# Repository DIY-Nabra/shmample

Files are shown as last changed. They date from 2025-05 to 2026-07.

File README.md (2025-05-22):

Sh'mample
=========

Sh'mample is a shift register driven sample and hold sequencer, capable of rungling.
Inspired in equal parts by the Ciat-Lonbarde Man with the Red Steam, and the Buchla 264.

For use with Ciat-Lonbarde instruments.

[Guide](assets/guide.md)

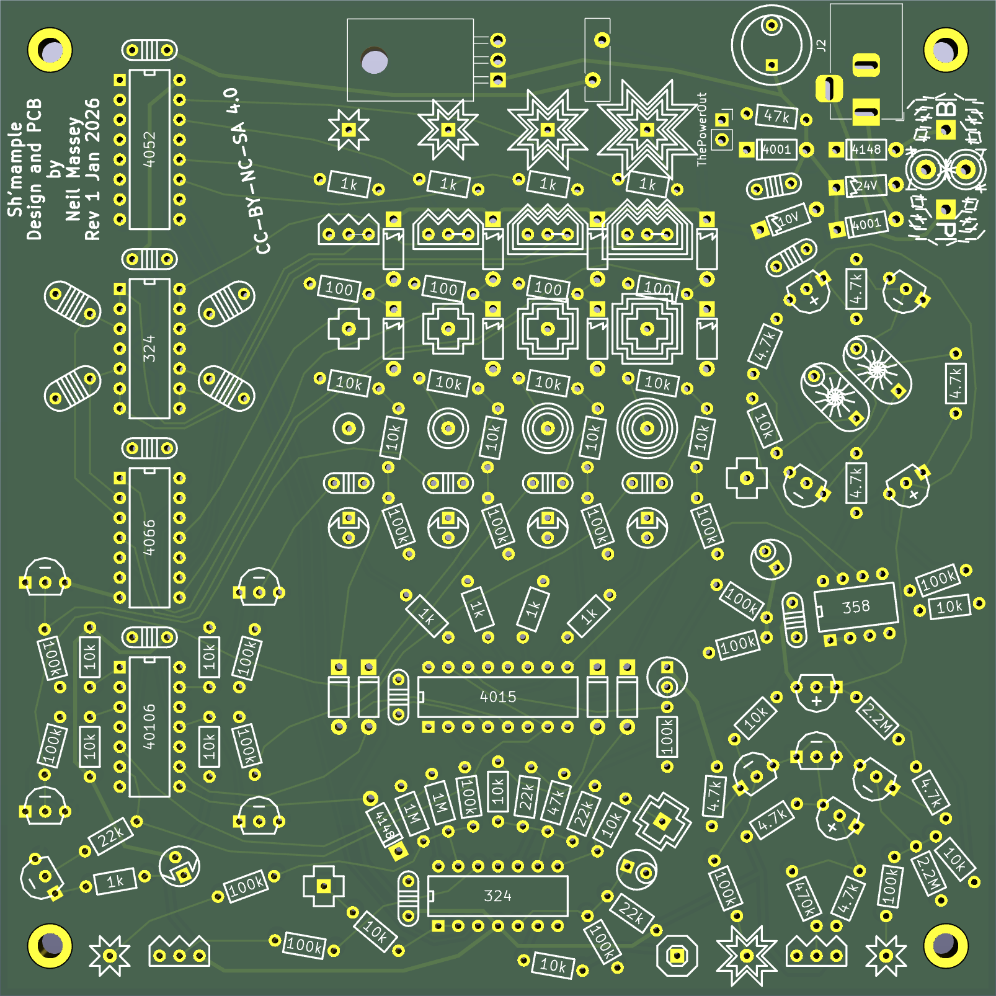
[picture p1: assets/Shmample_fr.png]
Shmample Front

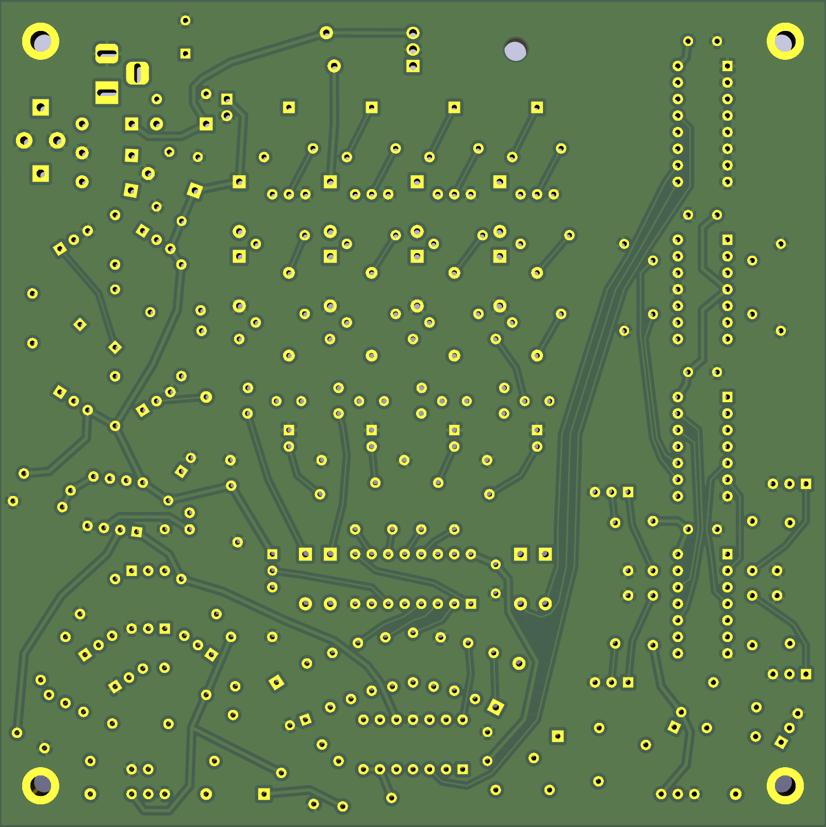
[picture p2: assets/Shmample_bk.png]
Shmample Back


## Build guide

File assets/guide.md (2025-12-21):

Sh'mample Guide
===============

Sh'mample consists of several circuit blocks, interacting:

1.  A clock, with rate nob control, plus verso and inverso inputs.  The special brown node is indicated on the circuit board.  Whether to connect it up is left as user choice.
2.  A comparator, deciding the input for the shift-register, comparing the Data In node with the Data Sense nob.  If nothing is connected here, the 2nd output from the shift register is taken as default input to the Data In node.
3.  A shift-register, driven by the clock.  If the default data input is taken, then the sample-and-hold will advance one stage at a time, tick-tock tick-tock.
4.  A four stage sample and hold, driven by the shift-register.  The Square Inputs provide the signals.  If the default data input is taken, then each stage will be sampled in turn, changing its output every 4th clock tick.  The attenuators can reduce the output sampled voltage.
5.  A single stage Selected Out.  If the default data input is taken, then each stage will be output here one after the other, just after it is sampled.  If an output is attenuated then it will also be attenuated when selected.
6.  Buffered outputs for each sample and hold at the Star Outputs.

Voltage references are provided so that stage 5 can act as a sequencer, outputting a different voltage each clock tick.  The attenuators on the outputs, in conjuction with the voltage reference, allows quite a conventional 4 stage sequencer to be patched.

The real fun happens when you plug something into the data input, where it acts something like a Klee sequencer, but sampling and holding between 1 and 4 sources per clock tick, and changing the selected output based on the contents of the shift-register.

The Circular Spike Inputs can be used to override the shift-register at each sample-and-hold.  Send a signal here to force that stage to sample-and-hold from the Square Input and present the signal at the Star Outputs.  These nodes are androgynous, and will also output a gate signal.

The Power Out can be used to power another board.  Such as the Fourses Tarp, for which this circuit was designed for.

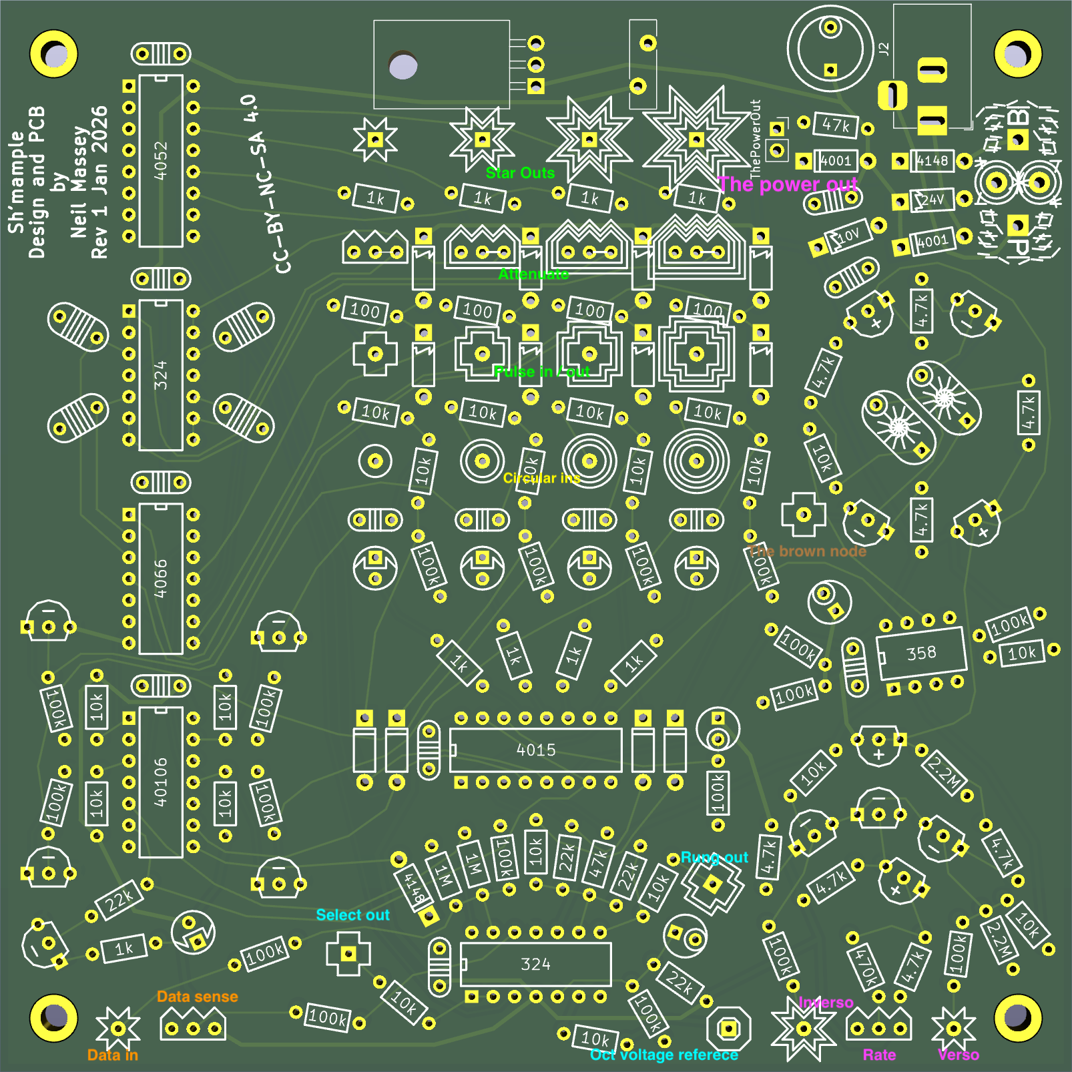
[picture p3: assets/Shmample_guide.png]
Shmample Guide


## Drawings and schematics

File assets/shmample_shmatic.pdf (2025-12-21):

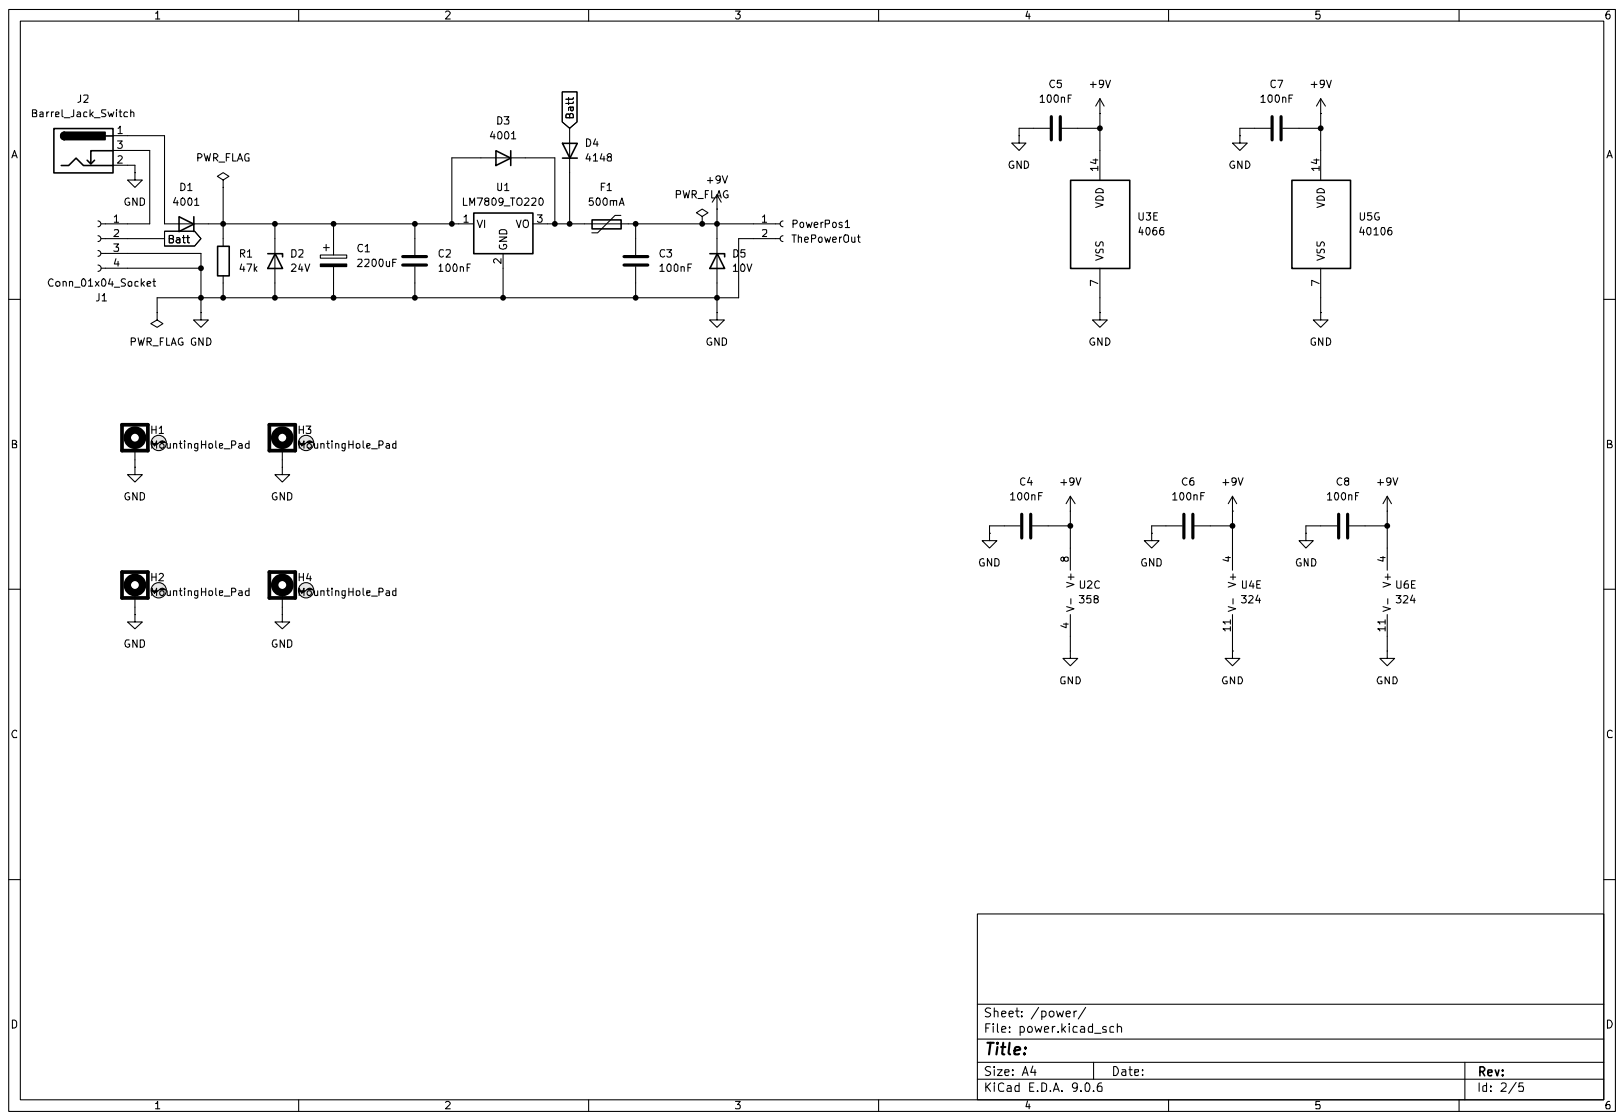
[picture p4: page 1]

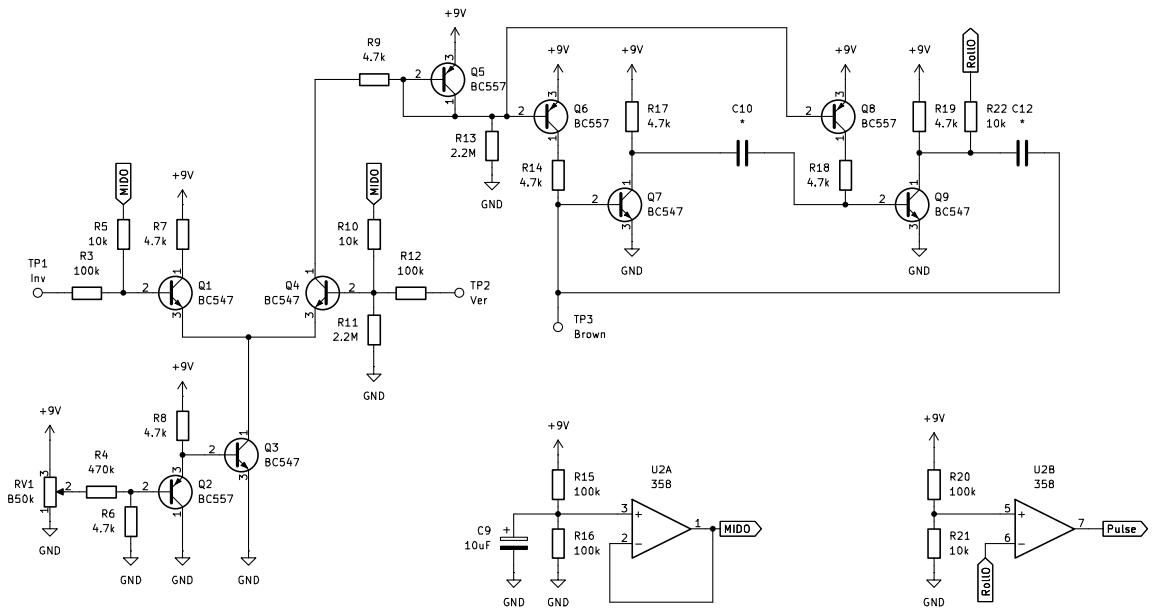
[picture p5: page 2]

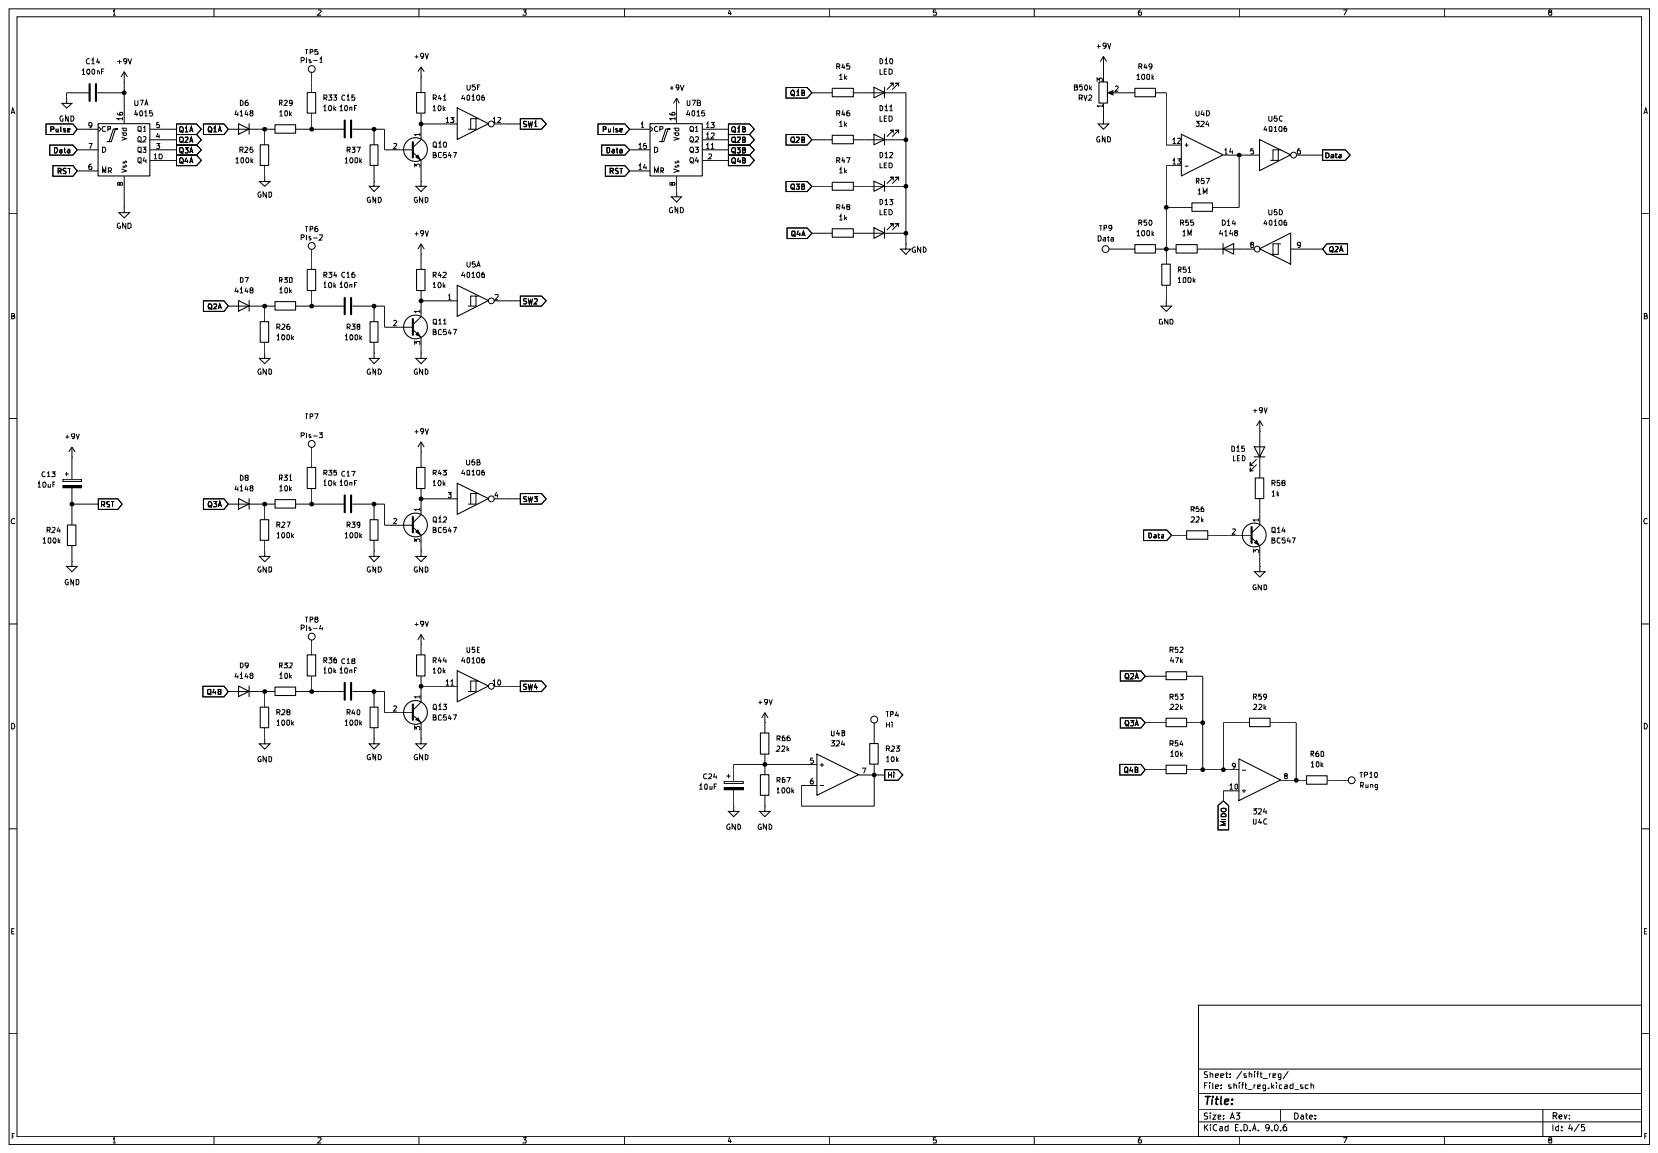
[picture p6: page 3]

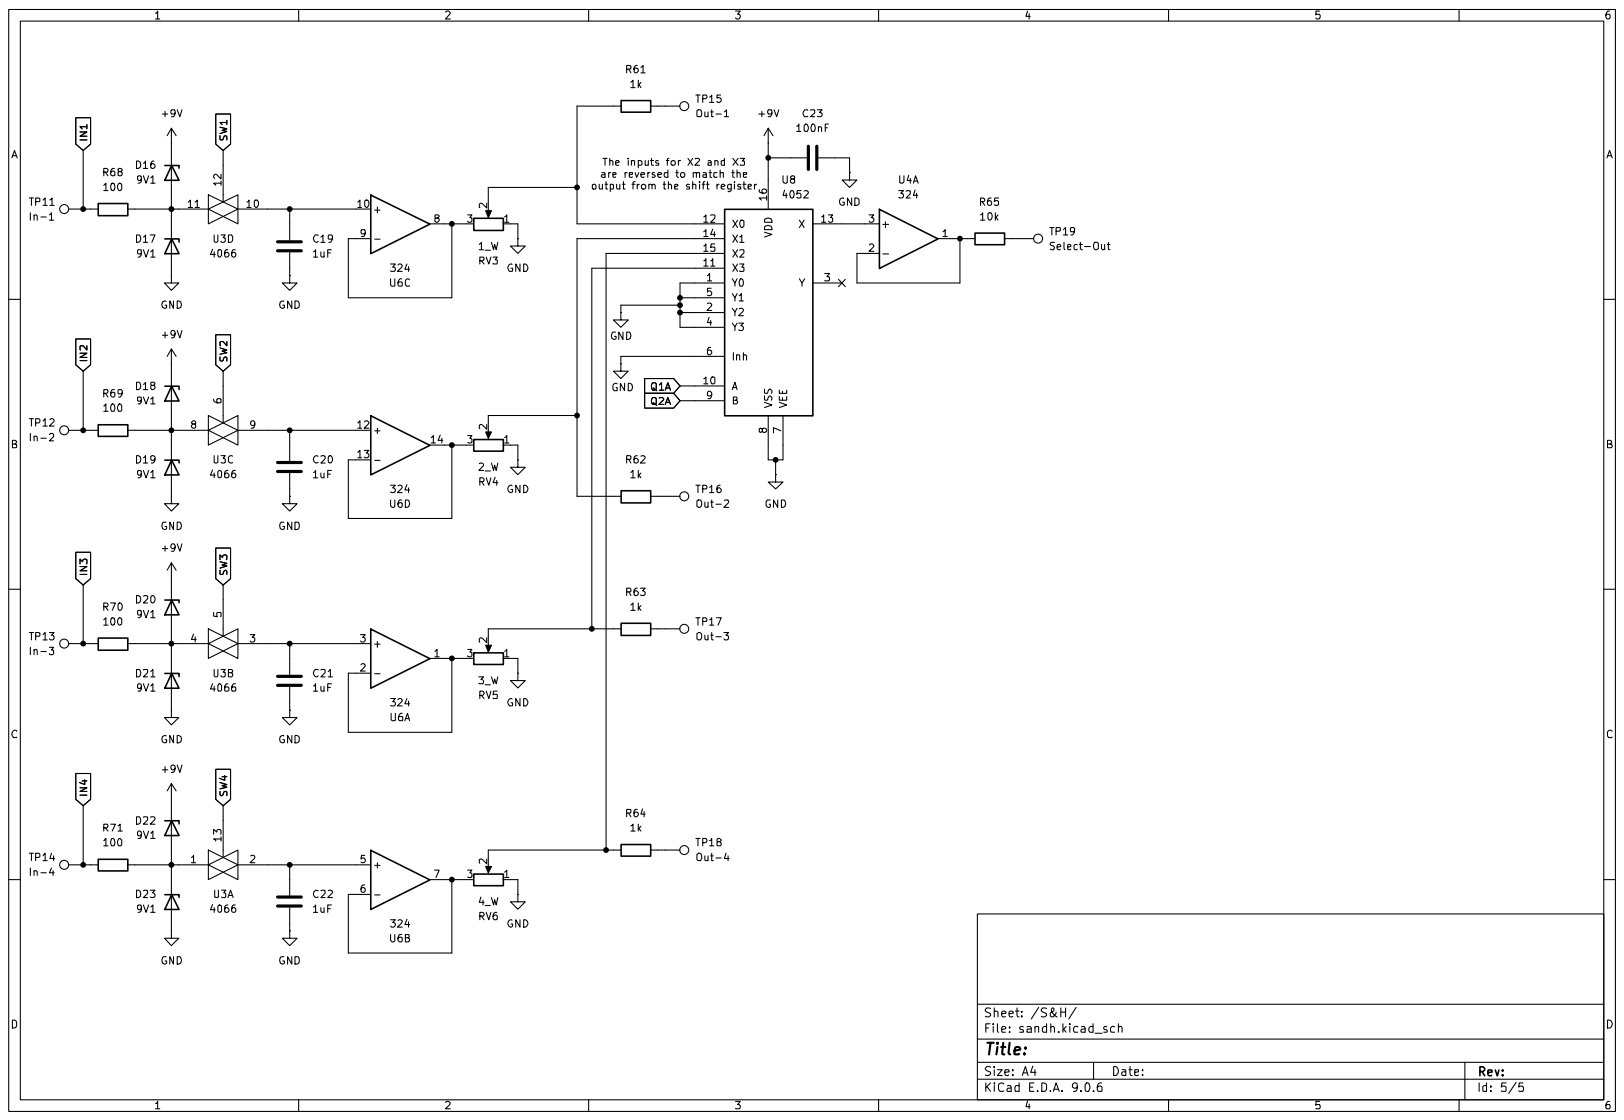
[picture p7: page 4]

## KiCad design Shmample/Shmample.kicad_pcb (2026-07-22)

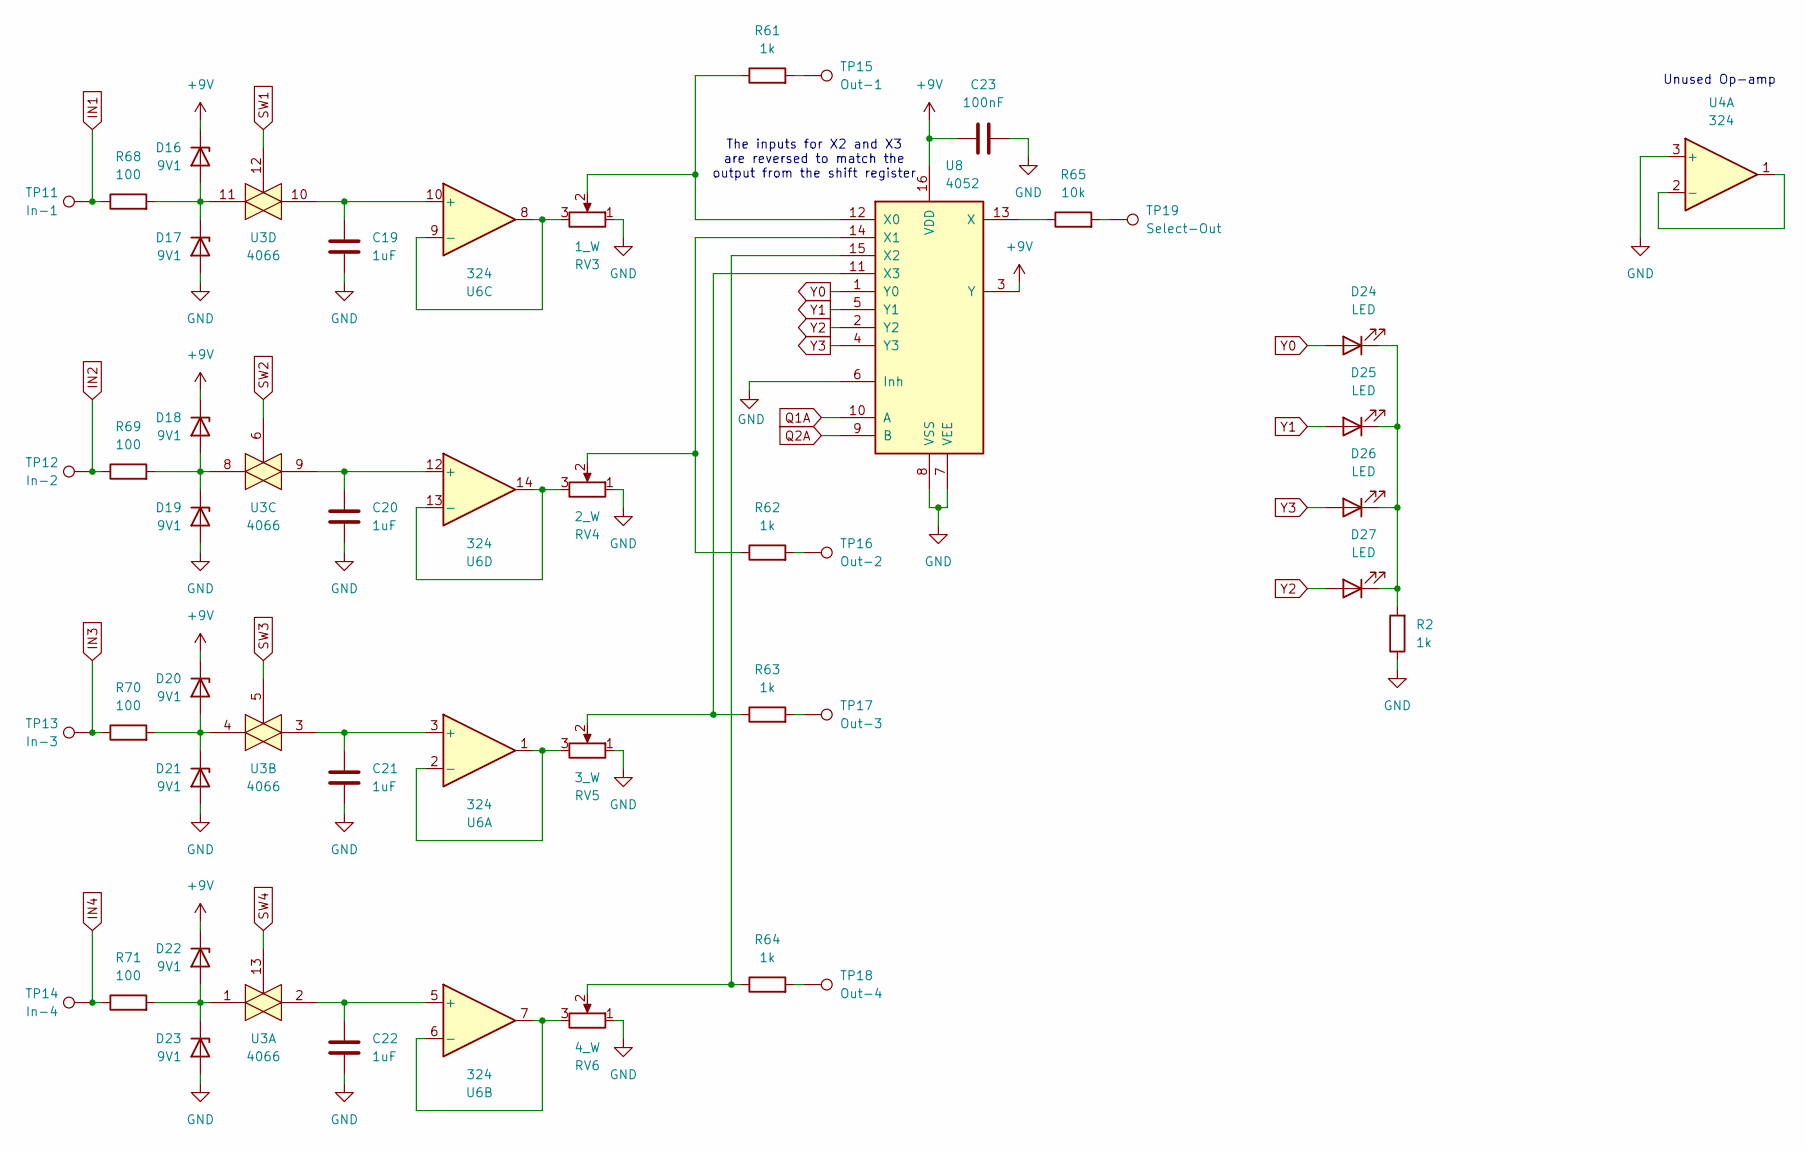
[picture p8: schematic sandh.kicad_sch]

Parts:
C19, C20, C21, C22: 1uF; cpoly105
C23: 100nF; cpoly104_small
D16, D17, D18, D19, D20, D21, D22, D23: 9V1; doz3
D24, D25, D26, D27: LED; led
R2, R61, R62, R63, R64: 1k; r3
R65: 10k; r3
R68, R69, R70, R71: 100; r3
RV3: 1_W; wnob1
RV4: 2_W; wnob2
RV5: 3_W; wnob3
RV6: 4_W; wnob4
TP11: In-1; wsquin
TP12: In-2; wsqout
TP13: In-3; wsqu3in
TP14: In-4; wsqu4in
TP15: Out-1; wtrin
TP16: Out-2; wtrin2
TP17: Out-3; wtrin3
TP18: Out-4; wtrin4
TP19: Select-Out; wsqout
U3: 4066; dip14
U4, U6: 324; dip14
U8: 4052; dip16

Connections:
+9V: C23.1, D16.1 (K), D18.1 (K), D20.1 (K), D22.1 (K), U8.3 (Y), U8.16 (VDD); also elsewhere on the board
GND: C19.2, C20.2, C21.2, C22.2, C23.2, D17.2 (A), D19.2 (A), D21.2 (A), D23.2 (A), R2.1, RV3.1, RV4.1, RV5.1, RV6.1, U4.3 (+), U8.6 (Inh), U8.7 (VEE), U8.8 (VSS); also elsewhere on the board
IN1: R68.1, TP11.1
IN2: R69.1, TP12.1
IN3: R70.1, TP13.1
IN4: R71.1, TP14.1
unnamed: D16.2 (A), D17.1 (K), R68.2, U3.11
unnamed: D18.2 (A), D19.1 (K), R69.2, U3.8
unnamed: D20.2 (A), D21.1 (K), R70.2, U3.4
unnamed: D22.2 (A), D23.1 (K), R71.2, U3.1
unnamed: D24.1 (K), D25.1 (K), D26.1 (K), D27.1 (K), R2.2
unnamed: R61.2, TP15.1
unnamed: R62.2, TP16.1
unnamed: R63.2, TP17.1
unnamed: R64.2, TP18.1
unnamed: R65.2, TP19.1
unnamed: U4.1, U4.2 (-)
unnamed: C21.1, U3.3, U6.3 (+)
unnamed: RV5.3, U6.1, U6.2 (-)
unnamed: C22.1, U3.2, U6.5 (+)
unnamed: RV6.3, U6.6 (-), U6.7
unnamed: C19.1, U3.10, U6.10 (+)
unnamed: RV3.3, U6.8, U6.9 (-)
unnamed: C20.1, U3.9, U6.12 (+)
unnamed: RV4.3, U6.13 (-), U6.14
unnamed: R61.1, RV3.2, U8.12 (X0)
unnamed: R62.1, RV4.2, U8.14 (X1)
unnamed: R64.1, RV6.2, U8.15 (X2)
unnamed: R63.1, RV5.2, U8.11 (X3)
unnamed: R65.1, U8.13 (X)
Q1A: U8.10 (A); also elsewhere on the board
Q2A: U8.9 (B); also elsewhere on the board
SW1: U3.12; also elsewhere on the board
SW2: U3.6; also elsewhere on the board
SW3: U3.5; also elsewhere on the board
SW4: U3.13; also elsewhere on the board
Y0: D24.2 (A), U8.1 (Y0)
Y1: D25.2 (A), U8.5 (Y1)
Y2: D27.2 (A), U8.2 (Y2)
Y3: D26.2 (A), U8.4 (Y3)

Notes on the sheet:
The inputs for X2 and X3 are reversed to match the output from the shift register
Unused Op-amp

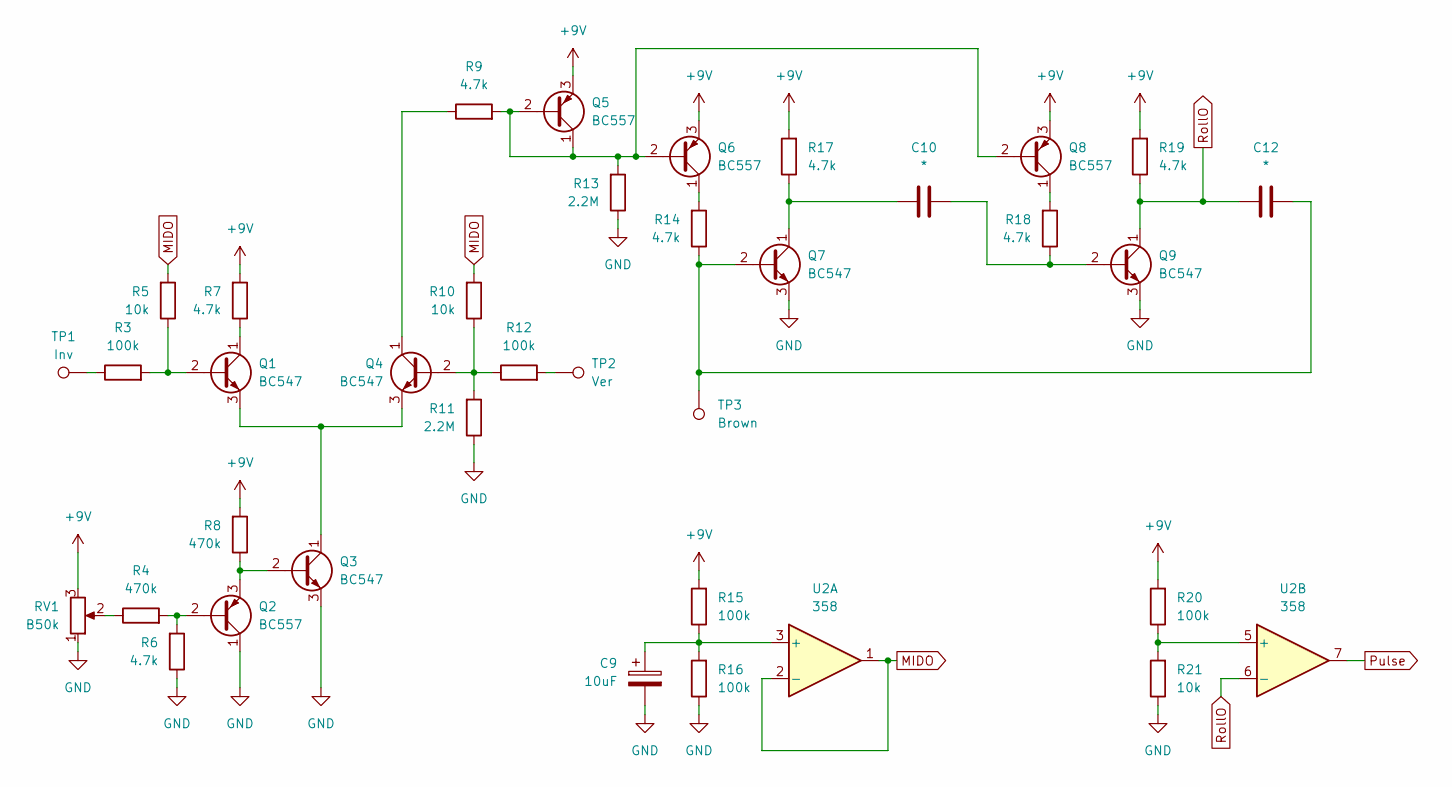
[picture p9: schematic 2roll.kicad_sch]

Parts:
C9: 10uF; cel1
C10, C12: *; chairy
Q1, Q3, Q4, Q7, Q9: BC547; qnpn
Q2, Q5, Q6, Q8: BC557; qpnp
R3, R12, R15, R16, R20: 100k; r3
R4, R8: 470k; r3
R5, R10, R21: 10k; r3
R6, R7, R9, R14, R17, R18, R19: 4.7k; r3
R11, R13: 2.2M; r3
RV1: B50k; wnob
TP1: Inv; wtrin2
TP2: Ver; wtrin
TP3: Brown; wsquin
U2: 358; dip8

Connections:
+9V: Q5.3 (E), Q6.3 (E), Q8.3 (E), R7.2, R8.2, R15.2, R17.2, R19.2, R20.2, RV1.3; also elsewhere on the board
GND: C9.2, Q2.1 (C), Q3.3 (E), Q7.3 (E), Q9.3 (E), R6.1, R11.1, R13.1, R16.1, R21.1, RV1.1; also elsewhere on the board
MIDO: R5.2, R10.2, U2.1, U2.2 (-); also elsewhere on the board
unnamed: Q1.2 (B), R3.2, R5.1
unnamed: Q1.1 (C), R7.1
unnamed: Q1.3 (E), Q3.1 (C), Q4.3 (E)
unnamed: Q2.2 (B), R4.2, R6.2
unnamed: Q2.3 (E), Q3.2 (B), R8.1
unnamed: Q4.2 (B), R10.1, R11.2, R12.1
unnamed: Q4.1 (C), R9.1
unnamed: Q5.1 (C), Q5.2 (B), Q6.2 (B), Q8.2 (B), R9.2, R13.2
unnamed: Q6.1 (C), R14.2
unnamed: C12.2, Q7.2 (B), R14.1, TP3.1
unnamed: C10.1, Q7.1 (C), R17.1
unnamed: Q8.1 (C), R18.2
unnamed: C10.2, Q9.2 (B), R18.1
unnamed: R3.1, TP1.1
unnamed: R4.1, RV1.2
unnamed: R12.2, TP2.1
unnamed: C9.1, R15.1, R16.2, U2.3 (+)
unnamed: R20.1, R21.2, U2.5 (+)
Pulse: U2.7; also elsewhere on the board
RollO: C12.1, Q9.1 (C), R19.1, U2.6 (-)

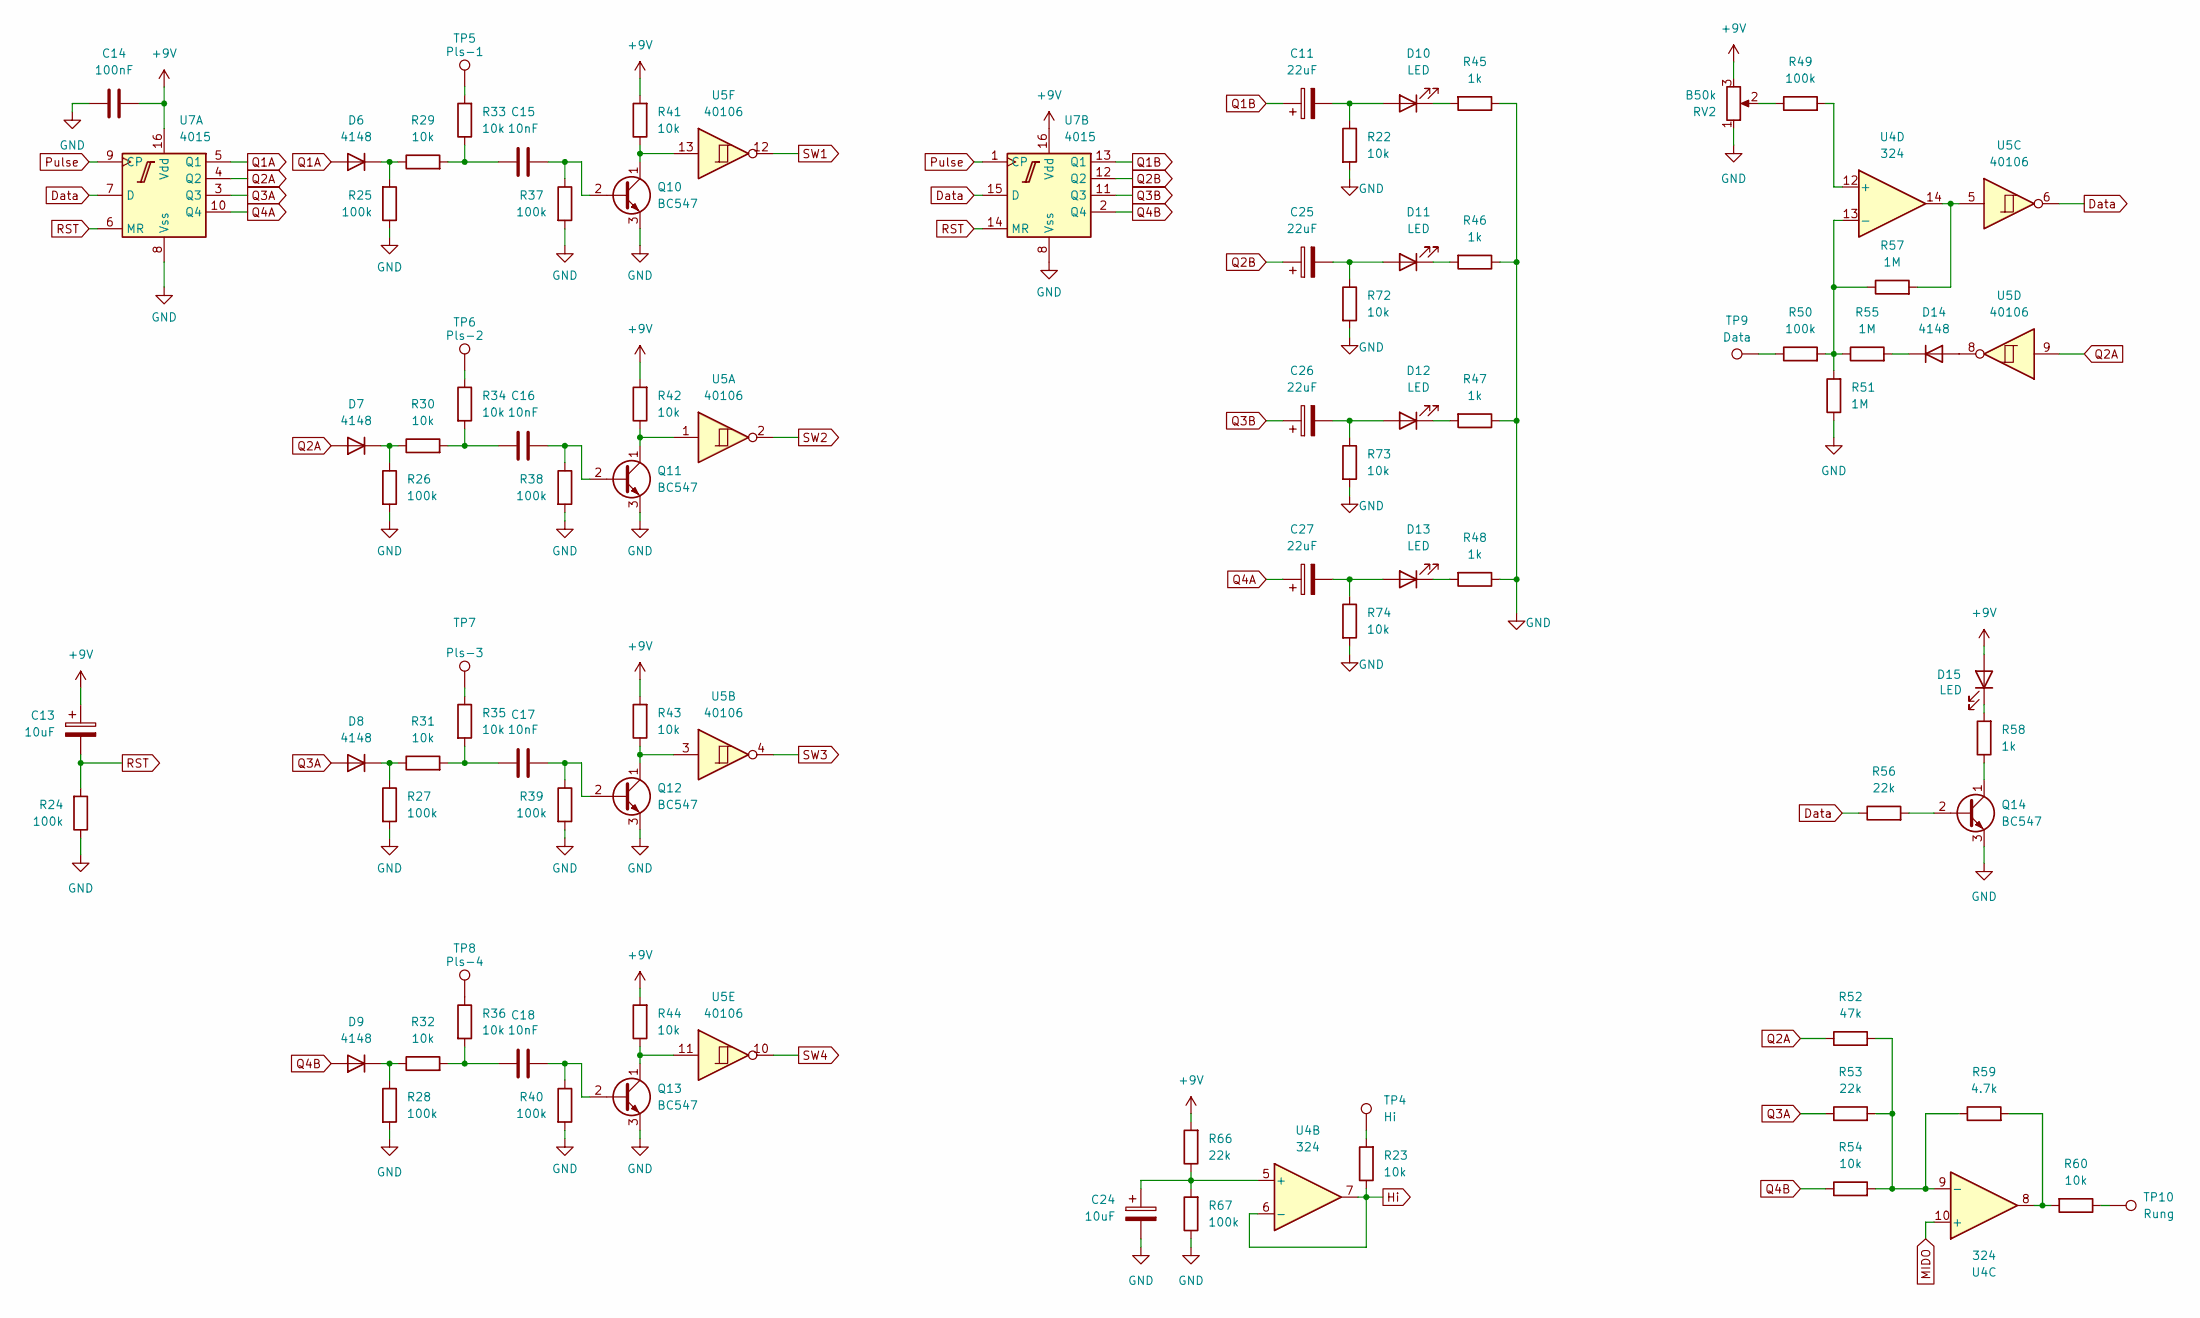
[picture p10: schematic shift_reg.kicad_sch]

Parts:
C11, C25, C26, C27: 22uF; cel1
C13, C24: 10uF; cel1
C14: 100nF; cpoly104_small
C15, C16, C17, C18: 10nF; cpoly103
D6, D7, D8, D9, D14: 4148; do3
D10, D11, D12, D13, D15: LED; led
Q10, Q11, Q12, Q13, Q14: BC547; qnpn
R22, R23, R29, R30, R31, R32, R33, R34, R35, R36, R41, R42, R43, R44, R54, R60, R72, R73, R74: 10k; r3
R24, R25, R26, R27, R28, R37, R38, R39, R40, R49, R50, R67: 100k; r3
R45, R46, R47, R48, R58: 1k; r3
R51, R55, R57: 1M; r3
R52: 47k; r3
R53, R56, R66: 22k; r3
R59: 4.7k; r3
RV2: B50k; wnob
TP4: Hi; wvout
TP5: Pls-1; wcircin
TP6: Pls-2; wcirc2in
TP7: Pls-3; wcirc3in
TP8: Pls-4; wcirc4in
TP9: Data; wtrin
TP10: Rung; wsqu2in
U4: 324; dip14
U5: 40106; dip14
U7: 4015; dip16

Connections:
+9V: C13.1, C14.2, D15.2 (A), R41.2, R42.2, R43.2, R44.2, R66.2, RV2.3, U7.16 (Vdd); also elsewhere on the board
Data: R56.1, U5.6, U7.7 (D), U7.15 (D)
GND: C14.1, C24.2, Q10.3 (E), Q11.3 (E), Q12.3 (E), Q13.3 (E), Q14.3 (E), R22.2, R24.1, R25.1, R26.2, R27.2, R28.2, R37.2, R38.2, R39.2, R40.2, R45.1, R46.1, R47.1, R48.1, R51.1, R67.1, R72.2, R73.2, R74.2, RV2.1, U7.8 (Vss); also elsewhere on the board
Hi: R23.1, U4.6 (-), U4.7
MIDO: U4.10 (+); also elsewhere on the board
unnamed: C15.1, R29.2, R33.1
unnamed: C16.1, R30.2, R34.2
unnamed: C17.1, R31.2, R35.2
unnamed: C18.1, R32.2, R36.2
unnamed: D6.1 (K), R25.2, R29.1
unnamed: D7.1 (K), R26.1, R30.1
unnamed: D8.1 (K), R27.1, R31.1
unnamed: D9.1 (K), R28.1, R32.1
unnamed: C11.2, D10.2 (A), R22.1
unnamed: D10.1 (K), R45.2
unnamed: C25.2, D11.2 (A), R72.1
unnamed: D11.1 (K), R46.2
unnamed: C26.2, D12.2 (A), R73.1
unnamed: D12.1 (K), R47.2
unnamed: C27.2, D13.2 (A), R74.1
unnamed: D13.1 (K), R48.2
unnamed: D14.2 (A), U5.8
unnamed: D14.1 (K), R55.2
unnamed: D15.1 (K), R58.2
unnamed: C15.2, Q10.2 (B), R37.1
unnamed: Q10.1 (C), R41.1, U5.13
unnamed: C16.2, Q11.2 (B), R38.1
unnamed: Q11.1 (C), R42.1, U5.1
unnamed: C17.2, Q12.2 (B), R39.1
unnamed: Q12.1 (C), R43.1, U5.3
unnamed: C18.2, Q13.2 (B), R40.1
unnamed: Q13.1 (C), R44.1, U5.11
unnamed: Q14.2 (B), R56.2
unnamed: Q14.1 (C), R58.1
unnamed: R23.2, TP4.1
unnamed: R33.2, TP5.1
unnamed: R34.1, TP6.1
unnamed: R35.1, TP7.1
unnamed: R36.1, TP8.1
unnamed: R49.1, RV2.2
unnamed: R50.1, TP9.1
unnamed: R57.2, U4.14, U5.5
unnamed: R59.2, R60.2, U4.8
unnamed: R60.1, TP10.1
unnamed: C24.1, R66.1, R67.2, U4.5 (+)
unnamed: R52.2, R53.2, R54.2, R59.1, U4.9 (-)
unnamed: R49.2, U4.12 (+)
unnamed: R50.2, R51.2, R55.1, R57.1, U4.13 (-)
Pulse: U7.1 (CP), U7.9 (CP); also elsewhere on the board
Q1A: D6.2 (A), U7.5 (Q1); also elsewhere on the board
Q1B: C11.1, U7.13 (Q1)
Q2A: D7.2 (A), R52.1, U5.9, U7.4 (Q2); also elsewhere on the board
Q2B: C25.1, U7.12 (Q2)
Q3A: D8.2 (A), R53.1, U7.3 (Q3)
Q3B: C26.1, U7.11 (Q3)
Q4A: C27.1, U7.10 (Q4)
Q4B: D9.2 (A), R54.1, U7.2 (Q4)
RST: C13.2, R24.2, U7.6 (MR), U7.14 (MR)
SW1: U5.12; also elsewhere on the board
SW2: U5.2; also elsewhere on the board
SW3: U5.4; also elsewhere on the board
SW4: U5.10; also elsewhere on the board

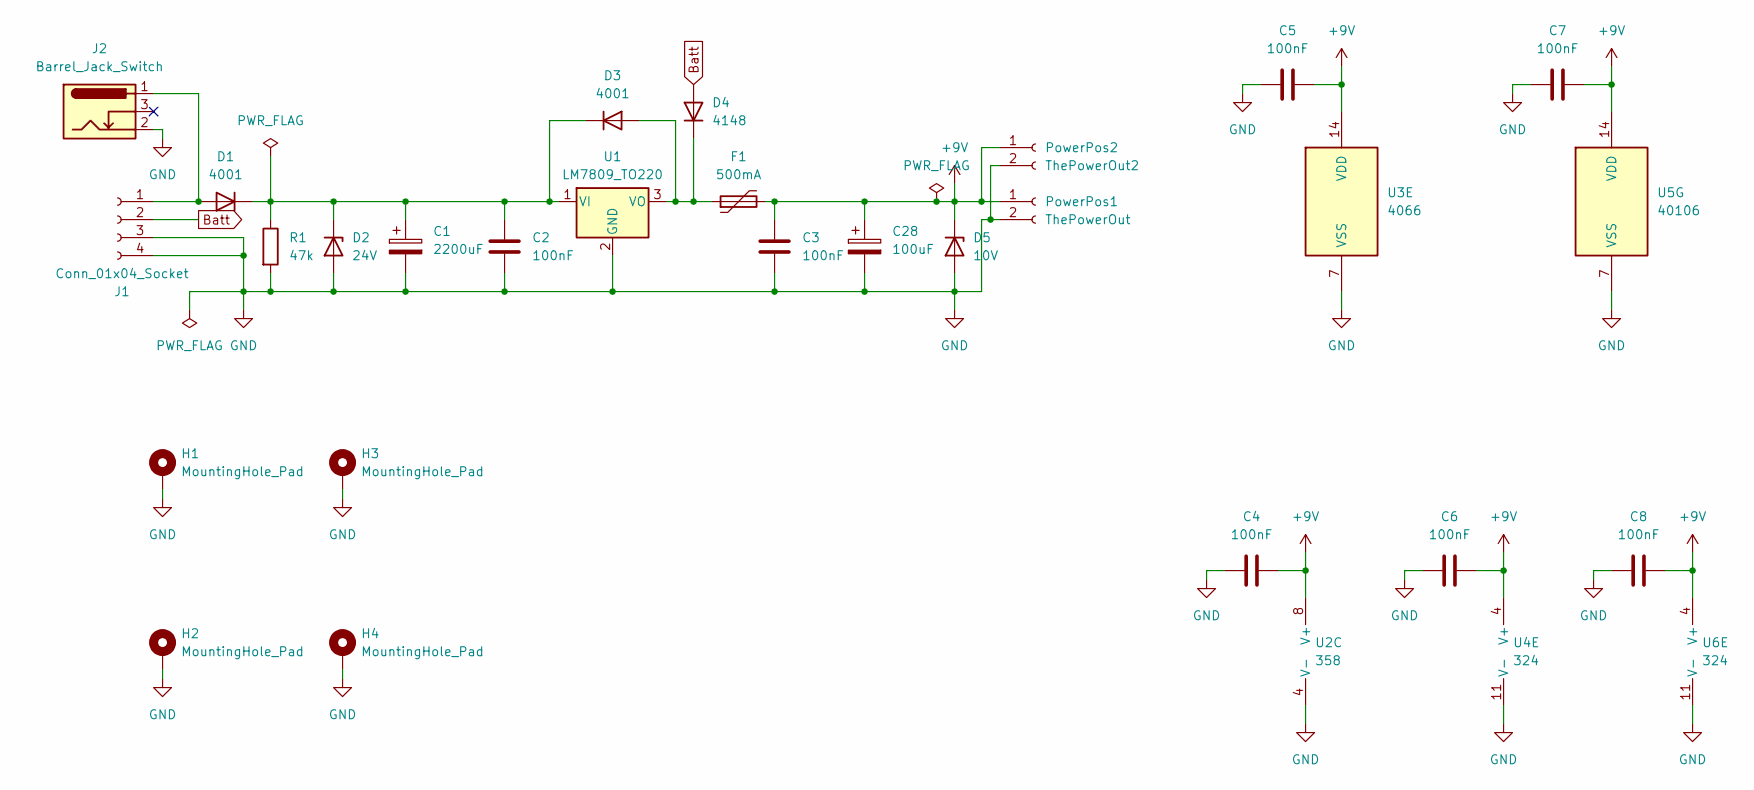
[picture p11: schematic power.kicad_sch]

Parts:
C1: 2200uF; cel2
C2, C3, C4, C5, C6, C7, C8: 100nF; cpoly104_small
C28: 100uF; cel2
D1, D3: 4001; do3
D2: 24V; doz3
D4: 4148; do3
D5: 10V; doz3
F1: 500mA; Fuse_Bourns_MF-RG500
H1, H2, H3, H4: MountingHole_Pad; MountingHole_3.2mm_M3_ISO7380_Pad
J1: Conn_01x04_Socket; powern
J2: Barrel_Jack_Switch; BarrelJack_Horizontal
PowerPos1: ThePowerOut; PinSocket_1x02_P2.54mm_Vertical
PowerPos2: ThePowerOut2; PinSocket_1x02_P2.54mm_Vertical
R1: 47k; r3
U1: LM7809_TO220; TO-220F-3_Horizontal_TabDown
U2: 358; dip8
U3: 4066; dip14
U4, U6: 324; dip14
U5: 40106; dip14

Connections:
+9V: C3.1, C4.2, C5.2, C6.2, C7.2, C8.2, C28.1, D5.1 (K), F1.2, PowerPos1.1, PowerPos2.1, U2.8 (V+), U3.14 (VDD), U4.4 (V+), U5.14 (VDD), U6.4 (V+); also elsewhere on the board
Batt: D4.2 (A), J1.2
GND: C1.2, C2.2, C3.2, C4.1, C5.1, C6.1, C7.1, C8.1, C28.2, D2.2 (A), D5.2 (A), H1.1, H2.1, H3.1, H4.1, J1.3, J1.4, J2.2, PowerPos1.2, PowerPos2.2, R1.2, U1.2 (GND), U2.4 (V-), U3.7 (VSS), U4.11 (V-), U5.7 (VSS), U6.11 (V-); also elsewhere on the board
unnamed: D1.2 (A), J1.1, J2.1
unnamed: C1.1, C2.1, D1.1 (K), D2.1 (K), D3.1 (K), R1.1, U1.1 (VI)
unnamed: D3.2 (A), D4.1 (K), F1.1, U1.3 (VO)

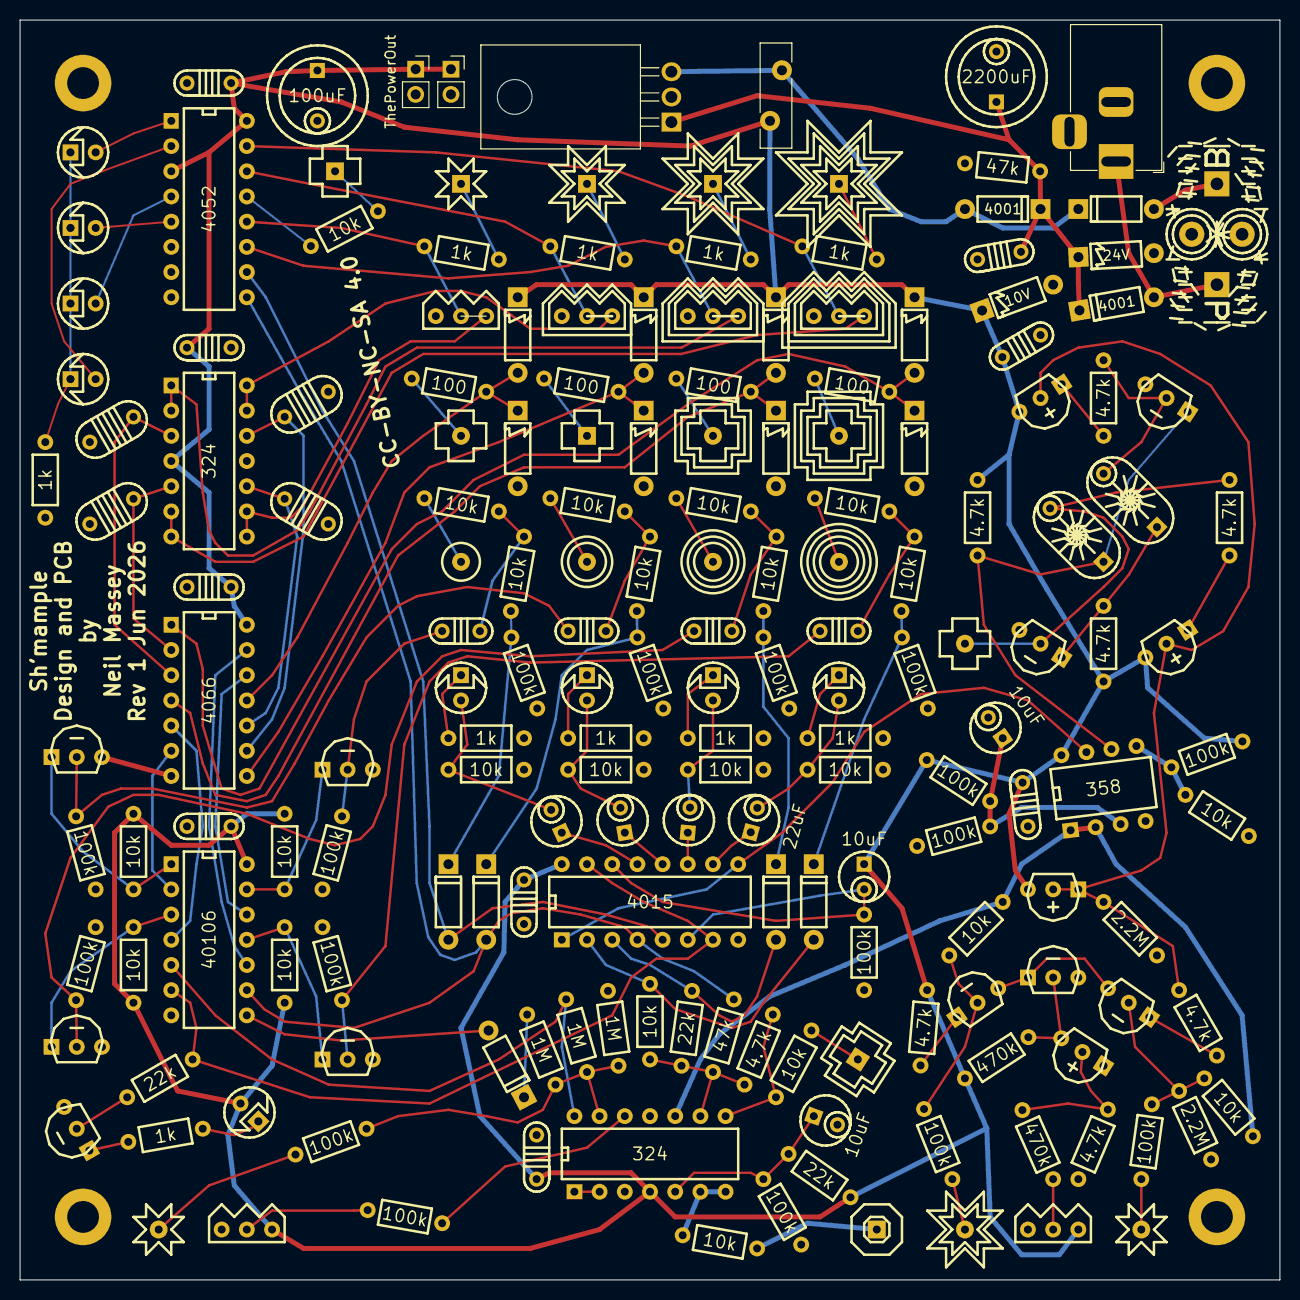
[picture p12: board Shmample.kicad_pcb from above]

Board: 2 copper layers, 127.0 x 127.0 mm, 185 parts (0 on the bottom side), 117 nets.

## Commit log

2025-05-22 Moved Shmample
    [Shmample.kicad_pcb, Shmample.kicad_sch]
2025-06-02 Added attenuators
    [Shmample.kicad_pcb, Shmample.kicad_sch]
2025-06-05 Rotated a pot. That is all
    [Shmample.kicad_pcb]
2025-06-05 Plussed up
    [Shmample.kicad_pcb]
2025-06-06 ironed out some kinky tracks
    [Shmample.kicad_pcb]
2025-11-24 Revision 1
    [2roll.kicad_sch, Shmample.kicad_pcb, Shmample.kicad_sch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]
2025-12-14 Big Pads
    [2roll.kicad_sch, Shmample.kicad_pcb, power.kicad_sch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]
2025-12-21 Added shmatic
    [Shmample.kicad_pcb, power.kicad_sch, sandh.kicad_sch]
2025-12-21 Just moved the rollz down a bit
    [Shmample.kicad_pcb]
2026-01-18 Final revision of revision 1 before manufacture
    [2roll.kicad_sch, Shmample.kicad_pcb, power.kicad_sch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]
2026-07-22 Some rejig before manufacture
    [Shmample.kicad_pcb, power.kicad_sch, sandh.kicad_sch]

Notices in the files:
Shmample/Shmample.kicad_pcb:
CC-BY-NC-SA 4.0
